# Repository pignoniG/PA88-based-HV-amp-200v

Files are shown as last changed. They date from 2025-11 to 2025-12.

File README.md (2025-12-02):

# PA88-based-HV-amp-200v
PA88 based HV amp 200v

This is (hopefully) a precision amplifier.
It is setup for 20x amplification and maximum output a bit over +-200v
Maximum output at higher frequency (> 20kHz) is limited. I will publish test data as I complete the project.

The power supply section is based on a design by https://www.changpuak.ch/electronics/VB408.php

It uses 2 A41-25-230L Transformers, these transformers can be configured both for 115V and 220V input. These are not 1:1 transformers, the 220V output is at rated current, with lower current voltage can be quite higher, I decided to wire them in reverse compared to the marking to have slightly lower voltage into the power supply, and avoid stressing the 400v capacitors.

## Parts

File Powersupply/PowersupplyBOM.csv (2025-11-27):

Id | Designator | Footprint | Quantity | Designation | Supplier and ref
1 | R6 | C_0805_2012Metric_Pad1.18x1.45mm_HandSolder | 1 | 7K5
2 | Q2 | SOT-223-3_TabPin2 | 1 | FZT458QTA
4 | C2 | CP_Radial_D30.0mm_P10.00mm_SnapIn | 1 | LAS2G101MELZ25
5 | D3,D4 | D_MiniMELF | 2 | TLZ10D-GS08
6 | R4,R2 | C_0805_2012Metric_Pad1.18x1.45mm_HandSolder | 2 | 470k
7 | I_SET1 | C_0805_2012Metric_Pad1.18x1.45mm_HandSolder | 1 | 39
8 | J2,J1 | Molex_KK-396_A-41791-0002_1x02_P3.96mm_Vertical | 2 | 26-60-4020
9 | D2,D1 | D_MiniMELF | 2 | LL4148-GS08
10 | U1 | TO-220-3_Vertical | 1 | IRFB9N60APBF
11 | V_SET1 | C_0805_2012Metric_Pad1.18x1.45mm_HandSolder | 1 | 634K
12 | C1 | CP_Radial_D12.5mm_P5.00mm | 1 | EEU-EB2G100
13 | HS1 | Heatsink_AAVID_Extruded_531102B02100G_34.9x12.7mm_H38.1mm | 1 | 531102B02100G
14 | U2,U3 | SOT-23-3 | 2 | LM431ACM3_NOPB
15 | D5 | Diode_Bridge_OnSemi_SDIP-4L | 1 | DF06S
16 | R1 | C_0805_2012Metric_Pad1.18x1.45mm_HandSolder | 1 | 390
17 | R5 | C_0805_2012Metric_Pad1.18x1.45mm_HandSolder | 1 | 16k
18 | Q1 | SOT-223-3_TabPin2 | 1 | FZT558TA
 |  | Headers & Wire Housings HSG 2P W/LKG RAMP | 4 | 09-50-3021
 |  | Headers & Wire Housings KK 156 TERMINAL CRIMP | 4 | 08-50-0015

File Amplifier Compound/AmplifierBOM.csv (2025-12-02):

Id | Designator | Footprint | Quantity | Designation | Supplier and ref
2 | C2,C5 | C_1206_3216Metric_Pad1.33x1.80mm_HandSolder | 2 | 200pf | C1206C201J5GACTU
3 | R13,R10 | R_1206_3216Metric_Pad1.30x1.75mm_HandSolder | 2 | 100k
4 | J1,J3 | Molex_KK-396_A-41791-0002_1x02_P3.96mm_Vertical | 2 |  | 26-60-4020
6 | R15,R8,R12,R14,R11 | R_1206_3216Metric_Pad1.30x1.75mm_HandSolder | 5 | 68k
7 | R6 | R_1206_3216Metric_Pad1.30x1.75mm_HandSolder | 1 | 11
8 | RV1 | Potentiometer_Bourns_3005_Horizontal | 1 | 10 | 3006P-1-100LF
9 | R9 | R_1206_3216Metric_Pad1.30x1.75mm_HandSolder | 1 | 68K
10 | D5,D6 | D_MiniMELF | 2 | D_Zener 6.2V | TZMB6V2-GS08
11 | R5,R4 | R_1206_3216Metric_Pad1.30x1.75mm_HandSolder | 2 | 49.9K | PLT1206Z5002AST5
13 | Termination | R_1206_3216Metric_Pad1.30x1.75mm_HandSolder | 1 | NC
14 | RV2 | Potentiometer_Bourns_3005_Horizontal | 1 | 100K | 3006P-1-104LF
16 | U1 | TO-3-8 | 1 | PA88
17 | C19,C20 | C_Elec_8x10.2 | 2 | 1.8u | UUB2G1R8MNL1GS
18 | R3 | R_1206_3216Metric_Pad1.30x1.75mm_HandSolder | 1 | 10M
19 | D1,D2 | D_SOD-123F | 2 |  | DSS120U
20 | D4,D3 | D_SMA_Handsoldering | 2 |  | SMAJ220A
21 | R7,R1 | R_1206_3216Metric_Pad1.30x1.75mm_HandSolder | 2 | 160
22 | R2 | R_1206_3216Metric_Pad1.30x1.75mm_HandSolder | 1 | 5.1K | TNPU12065K10BZEN00
23 | C3,C4 | C_1206_3216Metric_Pad1.33x1.80mm_HandSolder | 2 | 0.1u | C3216X7T2W104K160AE
25 | C1 | C_1206_3216Metric_Pad1.33x1.80mm_HandSolder | 1 | 15pF | 12067A150FAT2A

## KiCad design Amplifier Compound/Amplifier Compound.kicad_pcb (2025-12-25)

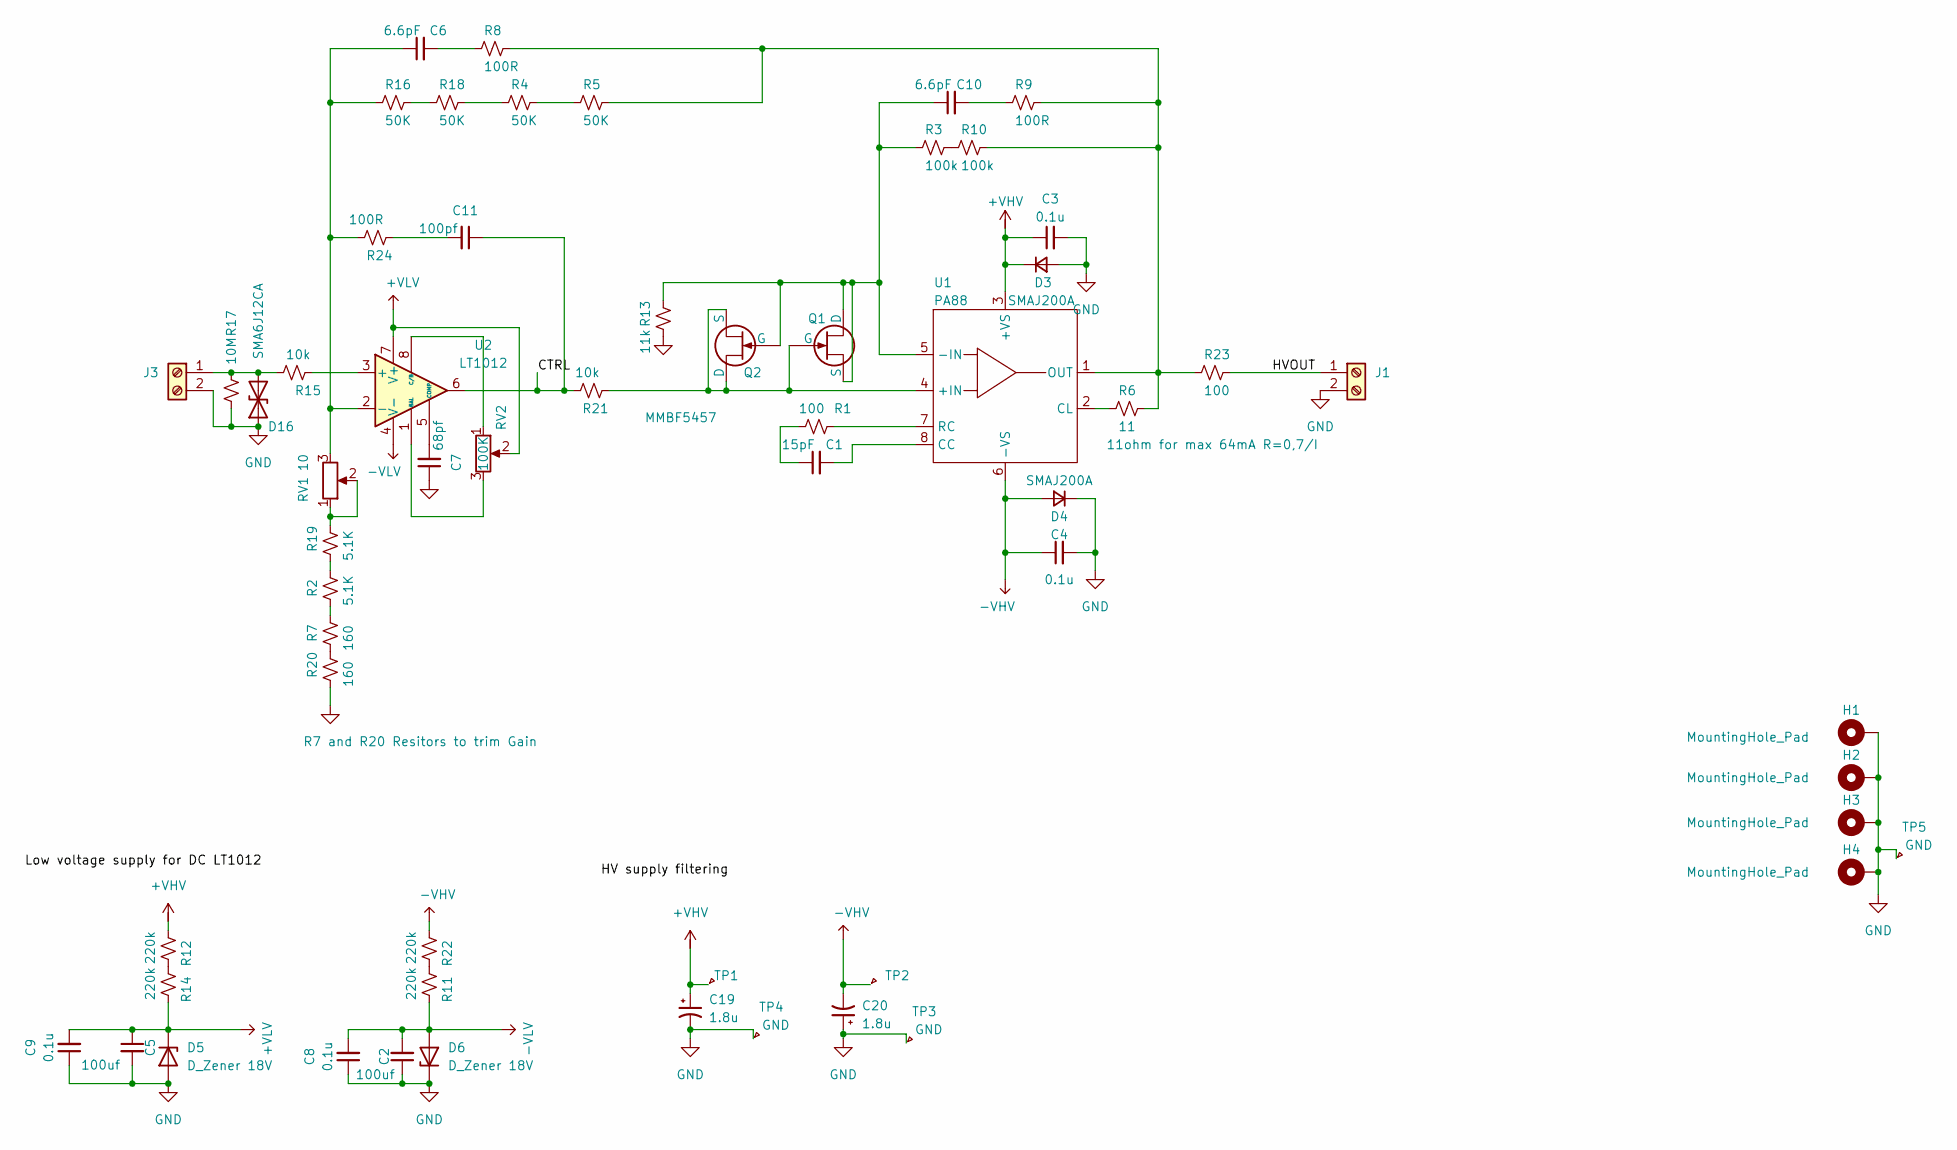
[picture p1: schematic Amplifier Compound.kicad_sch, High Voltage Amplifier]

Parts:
C1: 15pF; C_1206_3216Metric_Pad1.33x1.80mm_HandSolder; Voltage 50V; Part Description CAP CER 15PF 50V C0G/NP0 1206
C2: 100uf; CP_Elec_6.3x7.7; Voltage 25v
C3, C4, C8, C9: 0.1u; C_1206_3216Metric_Pad1.33x1.80mm_HandSolder; Voltage 450V; Part Description CAP CER 0.1UF 450V X7T 1206
C5: 100uf; CP_Elec_6.3x7.7; Voltage 24v
C6, C10: 6.6pF; C_1206_3216Metric_Pad1.33x1.80mm_HandSolder; Voltage 450V; Part Description CAP CER 15PF 450V C0G/NP0 1206
C7: 68pf; C_1206_3216Metric_Pad1.33x1.80mm_HandSolder; Voltage 50V; Part Description CAP CER 15PF 50V C0G/NP0 1206
C11: 100pf; C_1206_3216Metric_Pad1.33x1.80mm_HandSolder; Voltage 50V; Part Description CAP CER 15PF 50V C0G/NP0 1206
C19, C20: 1.8u; C_Elec_8x10.2; Voltage 400V; Mfg Part Number UUB2G1R8MNL1GS
D3, D4: SMAJ200A; D_SMA_Handsoldering; Mfg Part Number SMAJ200A-TP
D5, D6: D_Zener 18V; D_A-405_P10.16mm_Horizontal
D16: SMA6J12CA; D_SMA_Handsoldering; Mfg Part Number SMA6J5.0CA
H1, H2, H3, H4: MountingHole_Pad; MountingHole_3.2mm_M3_DIN965_Pad_TopBottom
J1, J3: Screw_Terminal_01x02; Molex_KK-396_A-41791-0002_1x02_P3.96mm_Vertical; Mfg Part Number 31101102
Q1, Q2: MMBF5457; SOT-23-3
R1: 100; R_1206_3216Metric_Pad1.30x1.75mm_HandSolder; Part Description RES SMD 100 OHM 1% 1/4W 1206
R2, R19: 5.1K; R_1206_3216Metric_Pad1.30x1.75mm_HandSolder; Part Description RES SMD 16.9K OHM 1% 1/4W 1206
R3, R10: 100k; R_1206_3216Metric_Pad1.30x1.75mm_HandSolder
R4, R5, R16, R18: 50K; R_1206_3216Metric_Pad1.30x1.75mm_HandSolder
R6: 11; R_1206_3216Metric_Pad1.30x1.75mm_HandSolder; Part Description RES 150 OHM 1% 1/2W 1206
R7, R20: 160; R_1206_3216Metric_Pad1.30x1.75mm_HandSolder; Part Description RES SMD 16.9K OHM 1% 1/4W 1206
R8, R9: 100R; R_1206_3216Metric_Pad1.30x1.75mm_HandSolder
R11, R12, R14, R22: 220k; R_Axial_DIN0411_L9.9mm_D3.6mm_P5.08mm_Vertical; Part Description RES SMD 16.9K OHM 1% 1/4W 1206
R13: 11k; R_1206_3216Metric_Pad1.30x1.75mm_HandSolder
R15, R21: 10k; R_1206_3216Metric_Pad1.30x1.75mm_HandSolder; Part Description RES SMD 100 OHM 1% 1/4W 1206
R17: 10M; R_1206_3216Metric_Pad1.30x1.75mm_HandSolder; Part Description RES SMD 100 OHM 1% 1/4W 1206
R23: 100; R_1206_3216Metric_Pad1.30x1.75mm_HandSolder; Part Description RES 150 OHM 1% 1/2W 1206
R24: 100R; R_1206_3216Metric_Pad1.30x1.75mm_HandSolder; Part Description RES SMD 100 OHM 1% 1/4W 1206
RV1: 10; Potentiometer_Bourns_3005_Horizontal; Mfg Part Number CT20EP503
RV2: 100K; Potentiometer_Bourns_3005_Horizontal; Mfg Part Number CT20EP503
TP1: +VHV; TestPoint_THTPad_2.5x2.5mm_Drill1.2mm
TP2: -VHV; TestPoint_THTPad_2.5x2.5mm_Drill1.2mm
TP3, TP4, TP5: GND; TestPoint_THTPad_2.5x2.5mm_Drill1.2mm
U1: PA88; TO-3-8; Mfg Part Number PA88
U2: LT1012; DIP-8_W7.62mm_LongPads

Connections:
+VHV: C3.1, C19.1, D3.1 (K), R12.2, TP1.1, U1.3 (+VS)
+VLV: C5.1, C9.2, D5.1 (K), R14.1, RV2.2, U2.7 (V+)
-VHV: C4.1, C20.2, D4.2 (A), R22.2, TP2.1, U1.6 (-VS)
-VLV: C2.2, C8.2, D6.2 (A), R11.1, U2.4 (V-)
/CTRL: C11.1, R21.1, U2.6
/HVOUT: J1.1, R23.1
GND: C2.1, C3.2, C4.2, C5.2, C7.1, C8.1, C9.1, C19.2, C20.1, D3.2 (A), D4.1 (K), D5.2 (A), D6.1 (K), D16.1 (A1), H1.1, H2.1, H3.1, H4.1, J1.2, J3.2, R13.2, R17.1, R20.2, TP3.1, TP4.1, TP5.1
unnamed: C1.1, R1.1
unnamed: C6.2, R8.2
unnamed: C10.2, R9.2
unnamed: C11.2, R24.2
unnamed: D16.2 (A2), J3.1, R15.2, R17.2
unnamed: C10.1, Q1.1 (D), Q1.2 (S), Q2.3 (G), R3.2, R13.1, U1.5 (-IN)
unnamed: Q1.3 (G), Q2.1 (D), Q2.2 (S), R21.2, U1.4 (+IN)
unnamed: R2.2, R7.1
unnamed: R4.1, R5.2
unnamed: R3.1, R10.2
unnamed: R11.2, R22.1
unnamed: R12.1, R14.2
unnamed: R16.1, R18.2
unnamed: R4.2, R18.1
unnamed: R19.1, RV1.1, RV1.2
unnamed: R2.1, R19.2
unnamed: R7.2, R20.1
unnamed: C1.2, U1.8 (CC)
unnamed: R6.2, U1.2 (CL)
unnamed: R5.1, R6.1, R8.1, R9.1, R10.1, R23.2, U1.1 (OUT)
unnamed: R1.2, U1.7 (RC)
unnamed: R15.1, U2.3 (+)
unnamed: C6.1, R16.2, R24.1, RV1.3, U2.2 (-)
unnamed: RV2.3, U2.1 (BAL)
unnamed: C7.2, U2.5 (COMP)
unnamed: RV2.1, U2.8 (C/B)

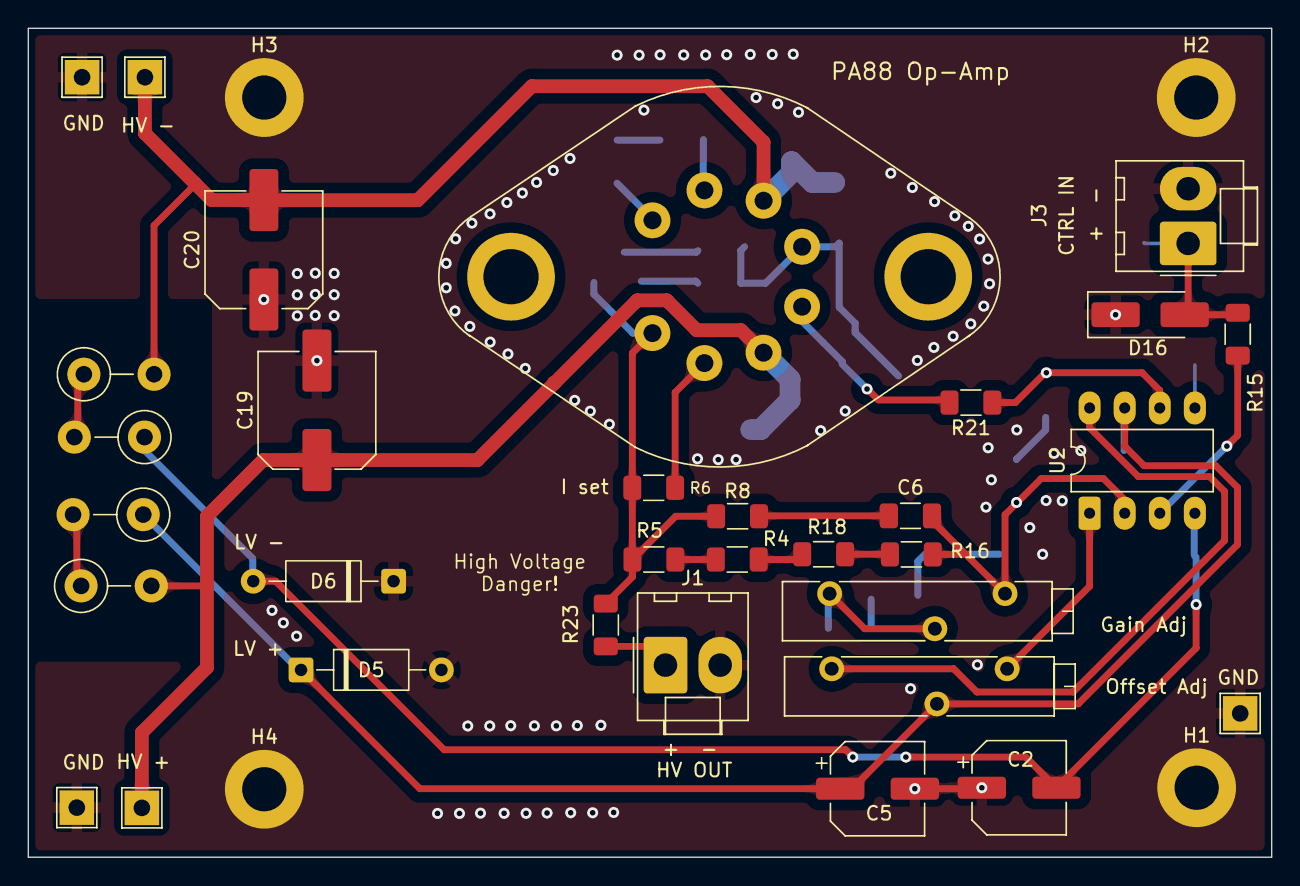
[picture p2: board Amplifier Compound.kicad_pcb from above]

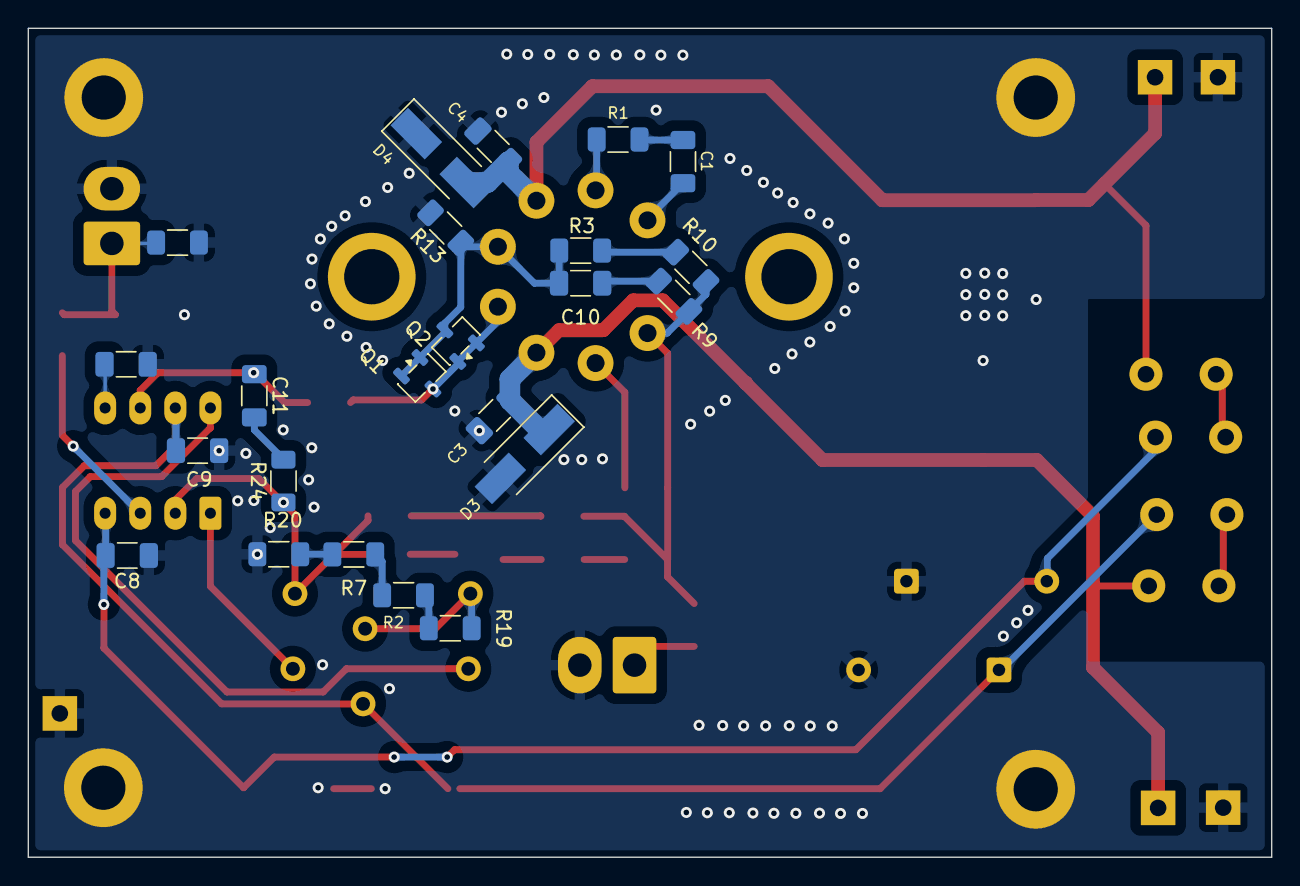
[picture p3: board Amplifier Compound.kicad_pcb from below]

Board: 2 copper layers, 90.0 x 60.0 mm, 59 parts (23 on the bottom side), 33 nets.

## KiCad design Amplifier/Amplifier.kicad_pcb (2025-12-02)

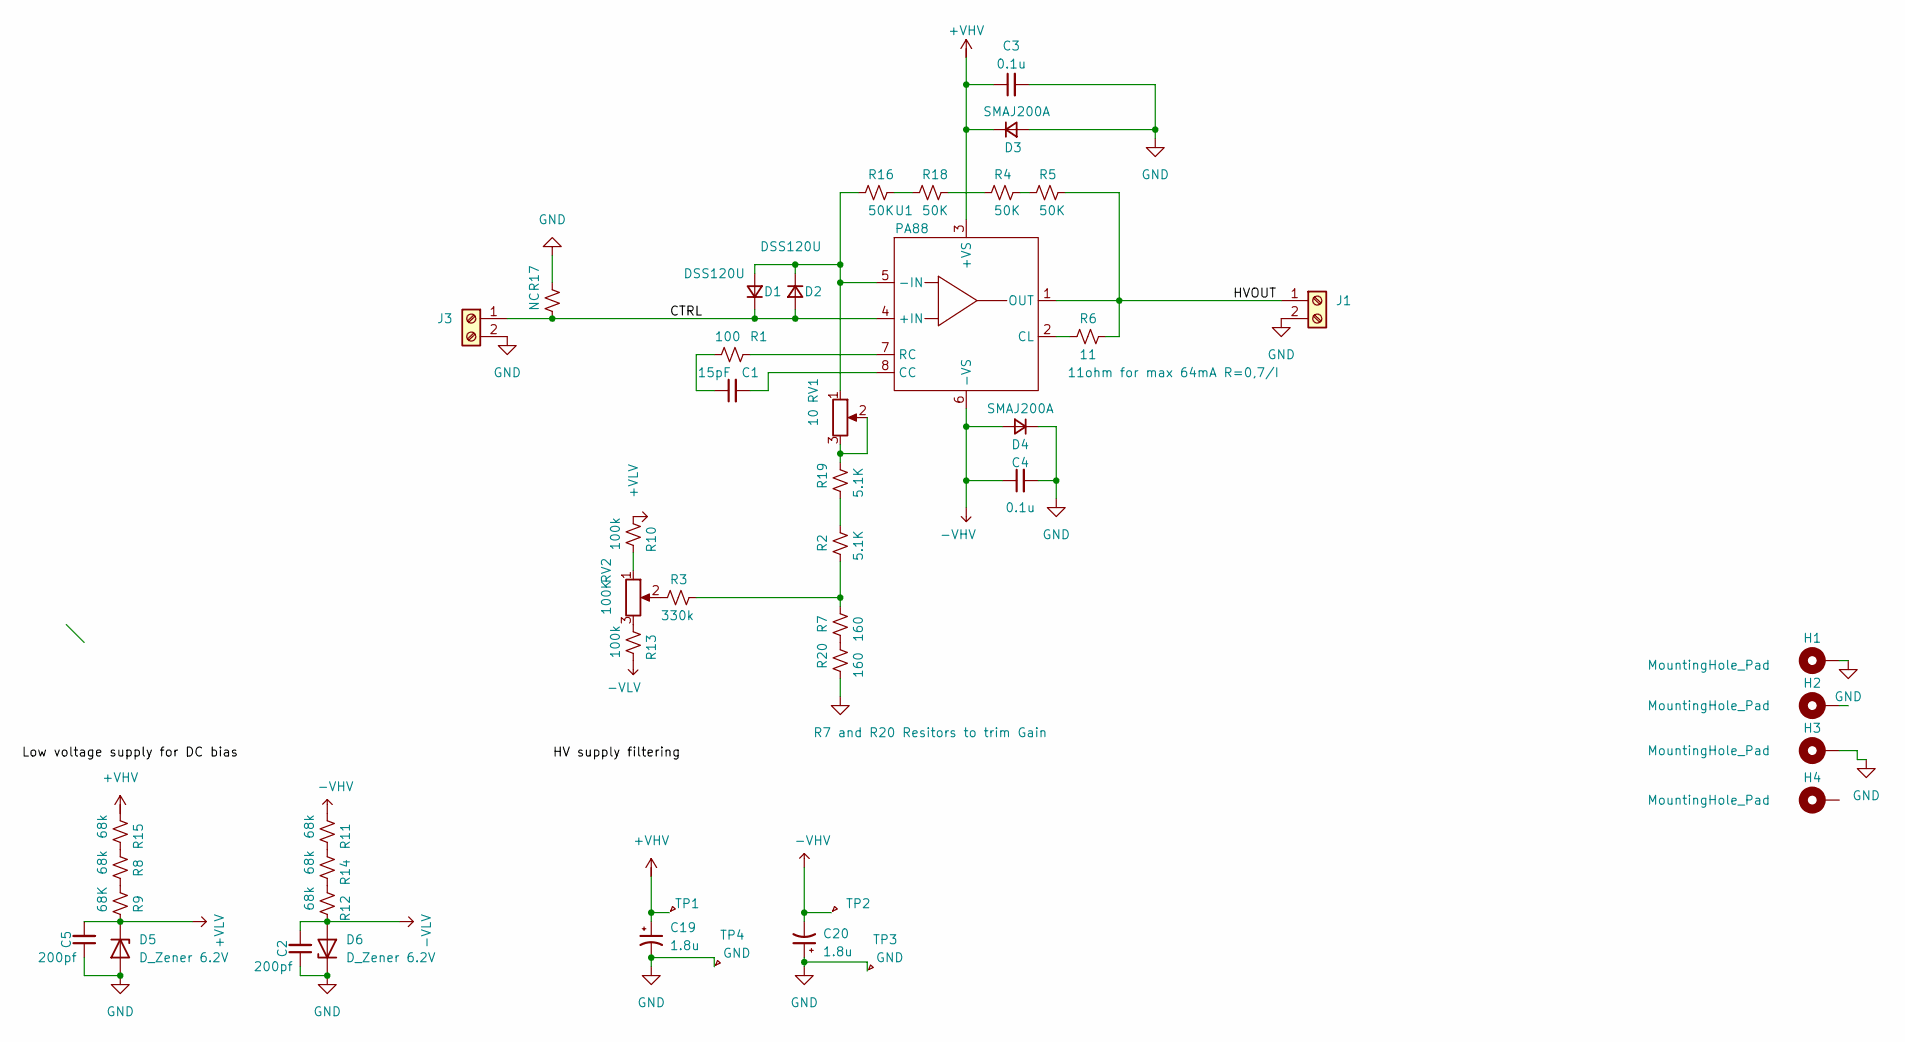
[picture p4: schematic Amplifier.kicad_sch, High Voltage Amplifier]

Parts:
C1: 15pF; C_1206_3216Metric_Pad1.33x1.80mm_HandSolder; Voltage 50V; Part Description CAP CER 15PF 50V C0G/NP0 1206
C2, C5: 200pf; C_1206_3216Metric_Pad1.33x1.80mm_HandSolder; Voltage 450V; Part Description CAP CER 0.1UF 450V X7T 1206
C3, C4: 0.1u; C_1206_3216Metric_Pad1.33x1.80mm_HandSolder; Voltage 450V; Part Description CAP CER 0.1UF 450V X7T 1206
C19, C20: 1.8u; C_Elec_8x10.2; Voltage 400V; Mfg Part Number UUB2G1R8MNL1GS
D1, D2: DSS120U; D_SOD-123F; Mfg Part Number DSS120U
D3, D4: SMAJ200A; D_SMA_Handsoldering; Mfg Part Number SMAJ200A-TP
D5, D6: D_Zener 6.2V; D_MiniMELF
H1, H2, H3, H4: MountingHole_Pad; MountingHole_3.2mm_M3_DIN965_Pad
J1, J3: Screw_Terminal_01x02; PhoenixContact_MCV_1,5_2-G-3.5_1x02_P3.50mm_Vertical; Mfg Part Number 31101102
R1: 100; R_1206_3216Metric_Pad1.30x1.75mm_HandSolder; Part Description RES SMD 100 OHM 1% 1/4W 1206
R2, R19: 5.1K; R_1206_3216Metric_Pad1.30x1.75mm_HandSolder; Part Description RES SMD 16.9K OHM 1% 1/4W 1206
R3: 330k; R_1206_3216Metric_Pad1.30x1.75mm_HandSolder; Part Description RES SMD 16.9K OHM 1% 1/4W 1206
R4, R5, R16, R18: 50K; R_1206_3216Metric_Pad1.30x1.75mm_HandSolder
R6: 11; R_1206_3216Metric_Pad1.30x1.75mm_HandSolder; Part Description RES 150 OHM 1% 1/2W 1206
R7, R20: 160; R_1206_3216Metric_Pad1.30x1.75mm_HandSolder; Part Description RES SMD 16.9K OHM 1% 1/4W 1206
R8, R11, R12, R14, R15: 68k; R_1206_3216Metric_Pad1.30x1.75mm_HandSolder; Part Description RES SMD 16.9K OHM 1% 1/4W 1206
R9: 68K; R_1206_3216Metric_Pad1.30x1.75mm_HandSolder; Part Description RES SMD 16.9K OHM 1% 1/4W 1206
R10, R13: 100k; R_1206_3216Metric_Pad1.30x1.75mm_HandSolder; Part Description RES SMD 16.9K OHM 1% 1/4W 1206
R17: NC; R_1206_3216Metric_Pad1.30x1.75mm_HandSolder; Part Description RES SMD 100 OHM 1% 1/4W 1206
RV1: 10; Potentiometer_Bourns_3005_Horizontal; Mfg Part Number CT20EP503
RV2: 100K; Potentiometer_Bourns_3005_Horizontal; Mfg Part Number CT20EP503
TP1: +VHV; TestPoint_THTPad_2.5x2.5mm_Drill1.2mm
TP2: -VHV; TestPoint_THTPad_2.5x2.5mm_Drill1.2mm
TP3, TP4: GND; TestPoint_THTPad_2.5x2.5mm_Drill1.2mm
U1: PA88; TO-3-8; Mfg Part Number PA88

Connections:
+VHV: C3.1, C19.1, D3.1 (K), R15.2, TP1.1, U1.3 (+VS)
+VLV: C5.2, D5.1 (K), R9.1, R10.2
-VHV: C4.1, C20.2, D4.2 (A), R11.2, TP2.1, U1.6 (-VS)
-VLV: C2.2, D6.2 (A), R12.1, R13.1
/CTRL: D1.1 (K), D2.2 (A), J3.1, R17.1, U1.4 (+IN)
/HVOUT: J1.1, R5.1, R6.1, U1.1 (OUT)
GND: C2.1, C3.2, C4.2, C5.1, C19.2, C20.1, D3.2 (A), D4.1 (K), D5.2 (A), D6.1 (K), H1.1, H3.1, J1.2, J3.2, R17.2, R20.2, TP3.1, TP4.1
unnamed: C1.1, R1.1
unnamed: D1.2 (A), D2.1 (K), R16.2, RV1.1, U1.5 (-IN)
unnamed: R2.2, R3.1, R7.1
unnamed: R3.2, RV2.2
unnamed: R4.1, R5.2
unnamed: R8.1, R9.2
unnamed: R10.1, RV2.1
unnamed: R11.1, R14.2
unnamed: R12.2, R14.1
unnamed: R13.2, RV2.3
unnamed: R8.2, R15.1
unnamed: R16.1, R18.2
unnamed: R4.2, R18.1
unnamed: R19.1, RV1.2, RV1.3
unnamed: R2.1, R19.2
unnamed: R7.2, R20.1
unnamed: C1.2, U1.8 (CC)
unnamed: R6.2, U1.2 (CL)
unnamed: R1.2, U1.7 (RC)

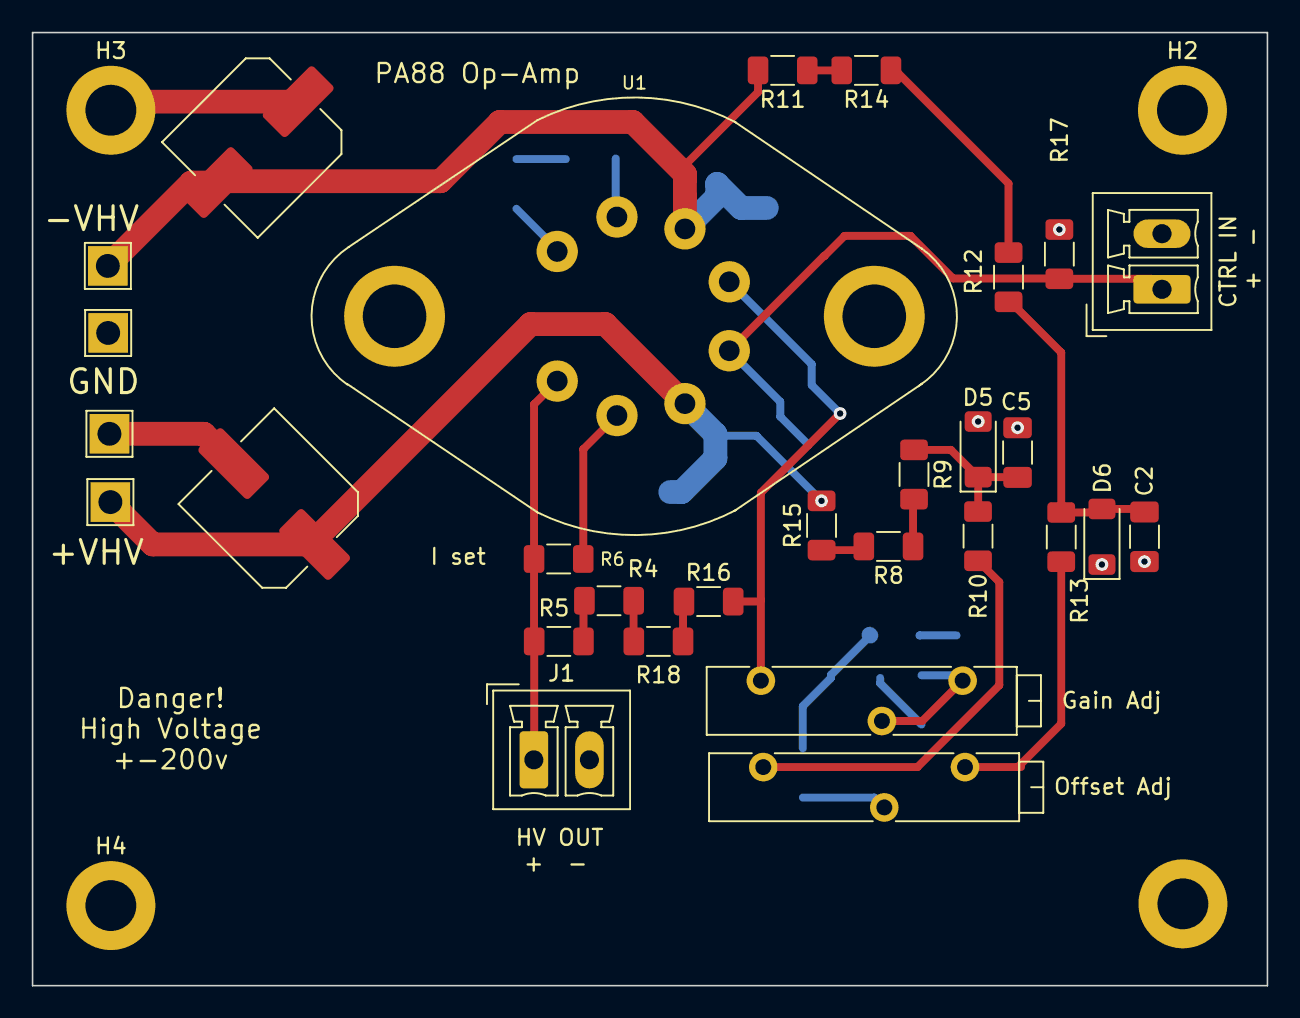
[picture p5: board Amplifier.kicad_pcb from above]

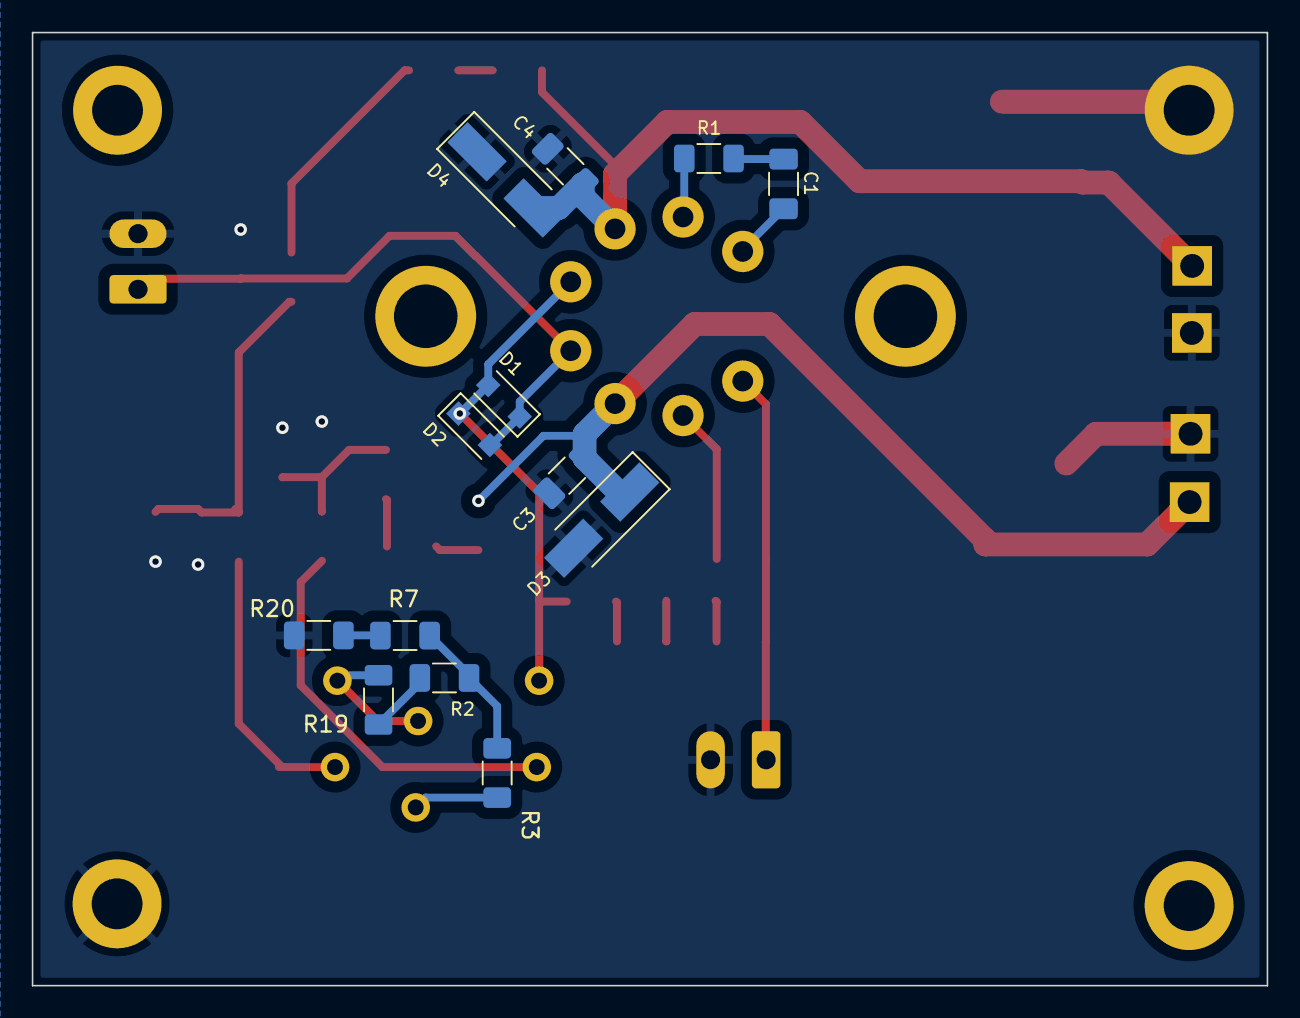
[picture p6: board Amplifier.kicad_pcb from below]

Board: 2 copper layers, 77.7 x 60.0 mm, 46 parts (13 on the bottom side), 26 nets.

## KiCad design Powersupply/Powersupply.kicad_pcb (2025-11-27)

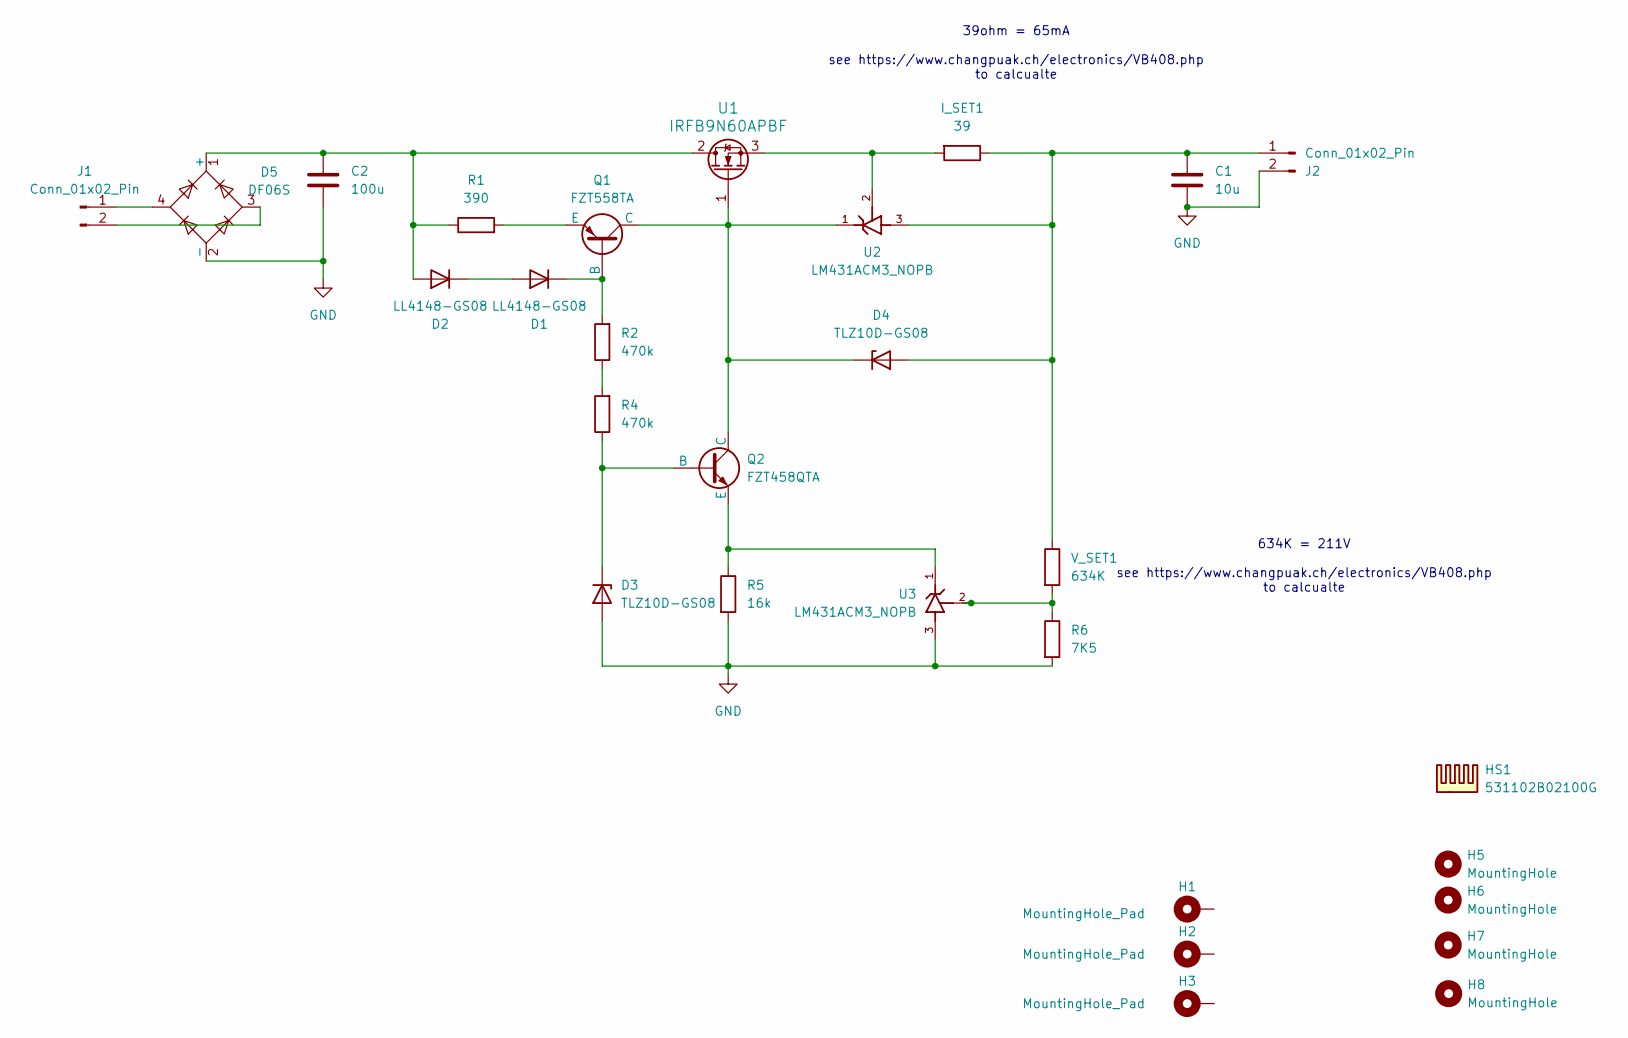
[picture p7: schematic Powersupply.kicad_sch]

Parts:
C1: 10u; CP_Radial_D12.5mm_P5.00mm
C2: 100u; CP_Radial_D30.0mm_P10.00mm_SnapIn
D1, D2: LL4148-GS08; D_MiniMELF
D3, D4: TLZ10D-GS08; D_MiniMELF
D5: DF06S; Diode_Bridge_OnSemi_SDIP-4L
H1, H2, H3: MountingHole_Pad; MountingHole_3.2mm_M3_DIN965_Pad
H5, H6, H7, H8: MountingHole; MountingHole_3mm
HS1: 531102B02100G; Heatsink_AAVID_Extruded_531102B02100G_34.9x12.7mm_H38.1mm
I_SET1: 39; C_0805_2012Metric_Pad1.18x1.45mm_HandSolder
J1, J2: Conn_01x02_Pin; Molex_KK-396_A-41791-0002_1x02_P3.96mm_Vertical
Q1: FZT558TA; SOT-223-3_TabPin2
Q2: FZT458QTA; SOT-223-3_TabPin2
R1: 390; C_0805_2012Metric_Pad1.18x1.45mm_HandSolder
R2, R4: 470k; C_0805_2012Metric_Pad1.18x1.45mm_HandSolder
R5: 16k; C_0805_2012Metric_Pad1.18x1.45mm_HandSolder
R6: 7K5; C_0805_2012Metric_Pad1.18x1.45mm_HandSolder
U1: IRFB9N60APBF; TO-220-3_Vertical
U2, U3: LM431ACM3_NOPB; SOT-23-3; PARTREV H
V_SET1: 634K; C_0805_2012Metric_Pad1.18x1.45mm_HandSolder

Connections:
GND: C1.2, C2.2, D3.2 (A), D5.2 (-), J2.2, R5.2, R6.2, U3.3
unnamed: D1.2 (A), D2.1 (K)
unnamed: D1.1 (K), Q1.1 (B), R2.2
unnamed: C2.1, D2.2 (A), D5.1 (+), R1.1, U1.2 (D)
unnamed: D3.1 (K), Q2.1 (B), R4.1
unnamed: C1.1, D4.2 (A), I_SET1.1, J2.1, U2.3, V_SET1.1
unnamed: D4.1 (K), Q1.2 (C), Q2.2 (C), U1.1 (G), U2.1
unnamed: D5.4, J1.1
unnamed: D5.3, J1.2
unnamed: Q1.3 (E), R1.2
unnamed: Q2.3 (E), R5.1, U3.1
unnamed: R2.1, R4.2
unnamed: R6.1, U3.2, V_SET1.2
unnamed: I_SET1.2, U1.3 (S), U2.2

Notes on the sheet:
634K = 211V see https://www.changpuak.ch/electronics/VB408.php to calcualte
39ohm = 65mA see https://www.changpuak.ch/electronics/VB408.php to calcualte

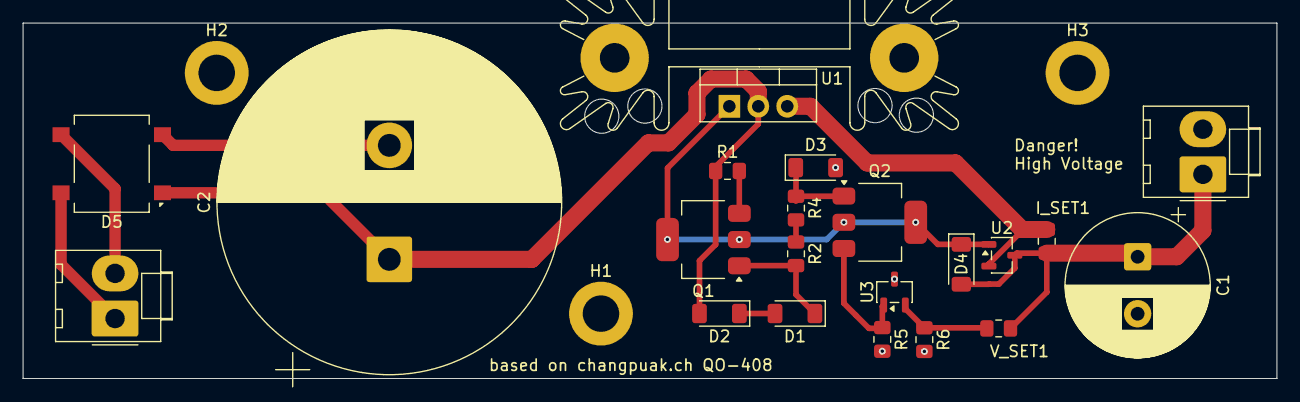
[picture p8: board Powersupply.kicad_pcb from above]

Board: 2 copper layers, 110.0 x 31.2 mm, 29 parts (0 on the bottom side), 14 nets.

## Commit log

2025-11-24 init frontpanel
    [hv amp front-B_Cu.gbr, hv amp front-B_Mask.gbr, hv amp front-B_Paste.gbr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]
2025-11-24 init all
    [Amplifier-B_Cu.gbr, Amplifier-B_Mask.gbr, Amplifier-B_Paste.gbr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]
2025-11-24 update amplifier
    [Amplifier-B_Cu.gbr, Amplifier-B_Mask.gbr, Amplifier-B_Paste.gbr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]
2025-12-02 update feedback resistor to 200k
    [Amplifier-B_Cu.gbr, Amplifier-B_Mask.gbr, Amplifier-B_Paste.gbr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]
2025-12-21 update composite
    [Amplifier Compound-B_Cu.gbr, Amplifier Compound-B_Mask.gbr, Amplifier Compound-B_Paste.gbr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]
2025-12-23 final components update
    [Amplifier Compound-B_Cu.gbr, Amplifier Compound-B_Mask.gbr, Amplifier Compound-B_Paste.gbr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]
2025-12-25 extra feedback
    [Amplifier Compound-B_Cu.gbr, Amplifier Compound-B_Mask.gbr, Amplifier Compound-B_Paste.gbr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]
